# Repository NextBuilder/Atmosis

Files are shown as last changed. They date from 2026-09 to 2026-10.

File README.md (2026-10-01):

<div align="center">

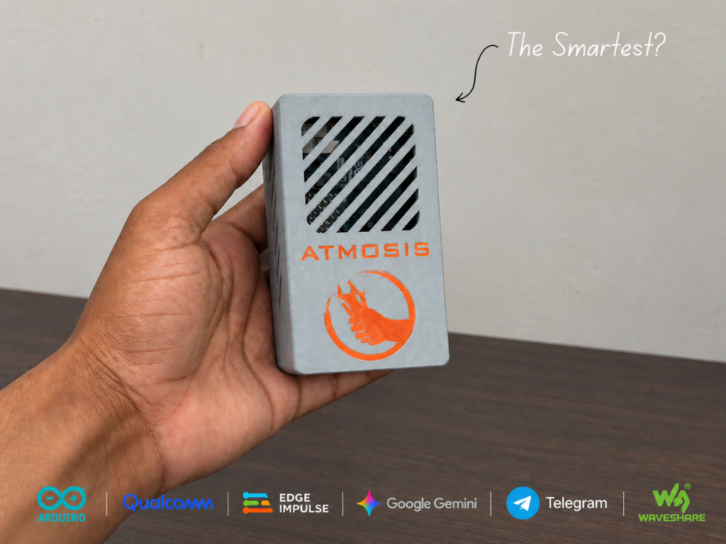
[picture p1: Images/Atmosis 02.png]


# Atmosis

**Real-world air intelligence, built on the Arduino UNO Q**

youtube (https://youtube.com/@NextBuilderIO)
instagram (https://instagram.com/next_builder)
x (https://x.com/NEXTBUILDERIO)
linkedin (https://www.linkedin.com/company/nextbuilderIO/)
instructables (https://www.instructables.com/member/Next%20Builder%20DIY/)
hackster (https://hackster.io/NEXTBUILDER)
hackaday (https://hackaday.io/NextBuilder)

</div>

## Overview

The air around us rarely announces itself. Exhaust from a busy road, dust from a building site, smoke from burning leaves, fumes from a kitchen, or a closed room slowly running out of fresh air — most of it is invisible, and almost none of it is measured.

**Atmosis** is a small device that watches the air every second and tells you what's going on. It turns nine sensor readings into one simple **air score from 1 to 100**, recognises the situation behind the numbers with an **Edge Impulse** model, and uses **Gemini 3.5 Flash** to suggest exactly what to do — on a live dashboard and on your phone through **Telegram**.

The safety features run on the board itself, so the light strip and the dust and carbon-monoxide alarms keep working even without the app or the internet.

## Highlights

- **Nine live readings** — IAQ, VOCs, formaldehyde, CO, PM2.5, temperature, humidity, pressure and altitude
- **Seven air patterns** — an Edge Impulse model trained on real data, from clean air to traffic, dust and smoke
- **Smart advice** — Gemini 3.5 Flash speaks up only when the air needs attention
- **Instant alerts** — clean Telegram cards and a daily air report
- **Live dashboard** — glass-style web app in light and dark themes
- **Works offline** — air score, light and alarms run on the microcontroller

## Dashboard

<div align="center">
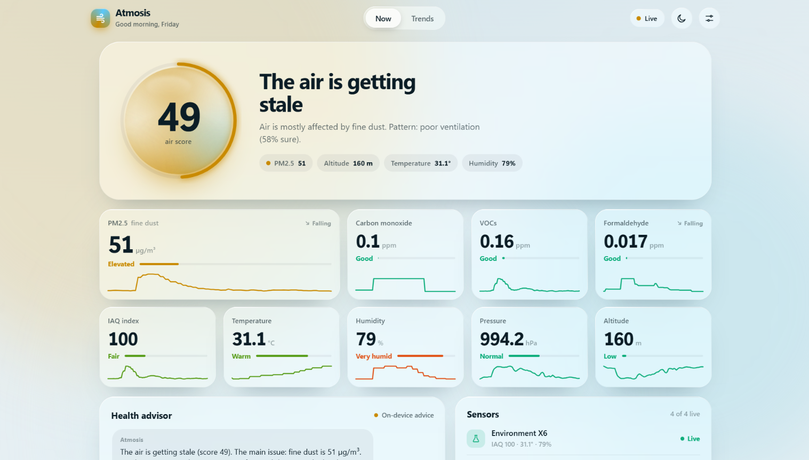
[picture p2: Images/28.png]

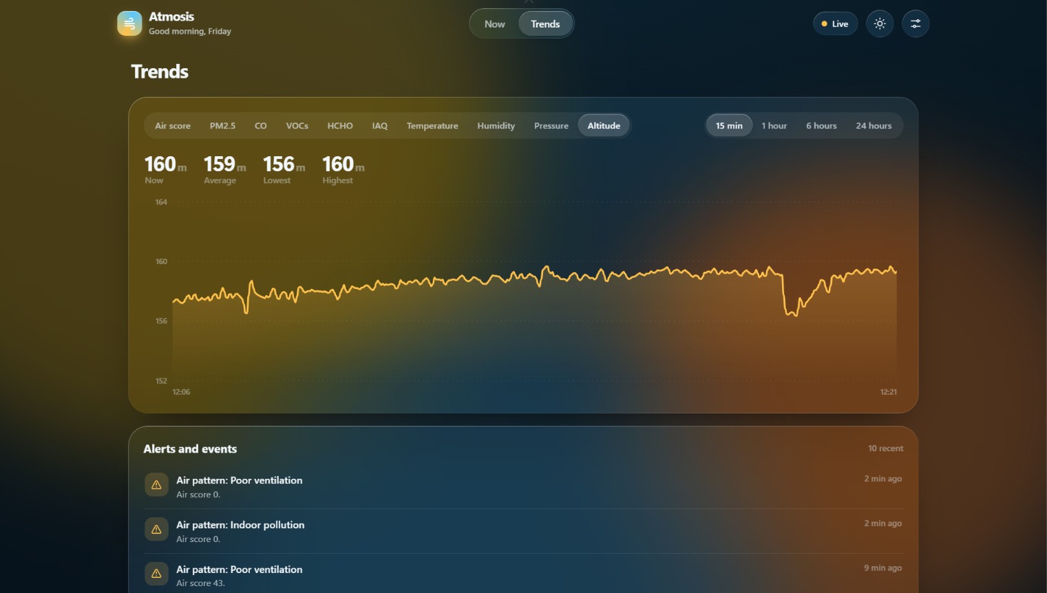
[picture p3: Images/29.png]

<br/>
<sub>Air score, live sensor tiles, Gemini health advisor and trends — in light and dark themes</sub>
</div>

## Telegram Alerts

<div align="center">
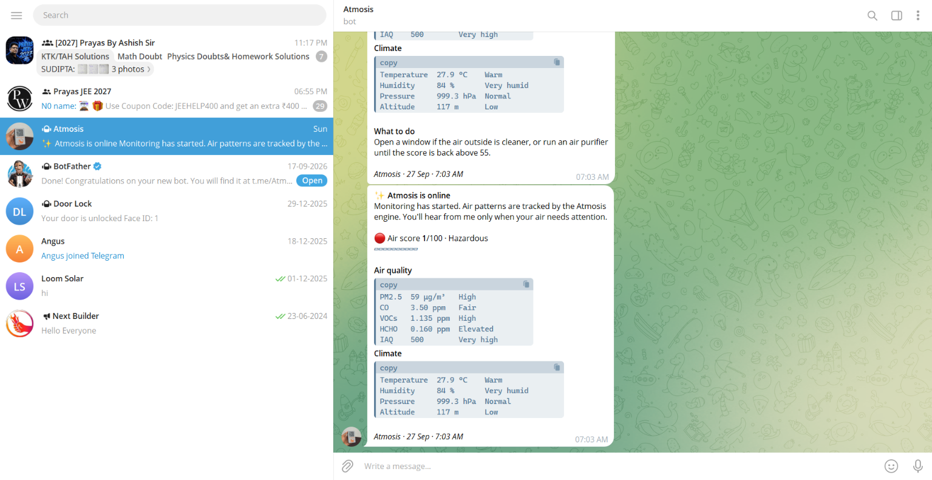
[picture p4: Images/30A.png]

</div>

Every alert is a short card with the air score, all readings, one clear action and a tip from Gemini.

| When | Alert |
|---|---|
| Air score drops to 35 | Air quality needs attention |
| PM2.5 goes above 150 µg/m³ | Very high dust level |
| CO goes above 9 ppm | Carbon monoxide alert, sent instantly |
| Indoor pollution or poor ventilation detected | Air pattern alert |
| Board silent for 2 minutes | Sensors offline |
| Every evening at 9 PM | Daily report with averages and peaks |

## How It Works

<div align="center">
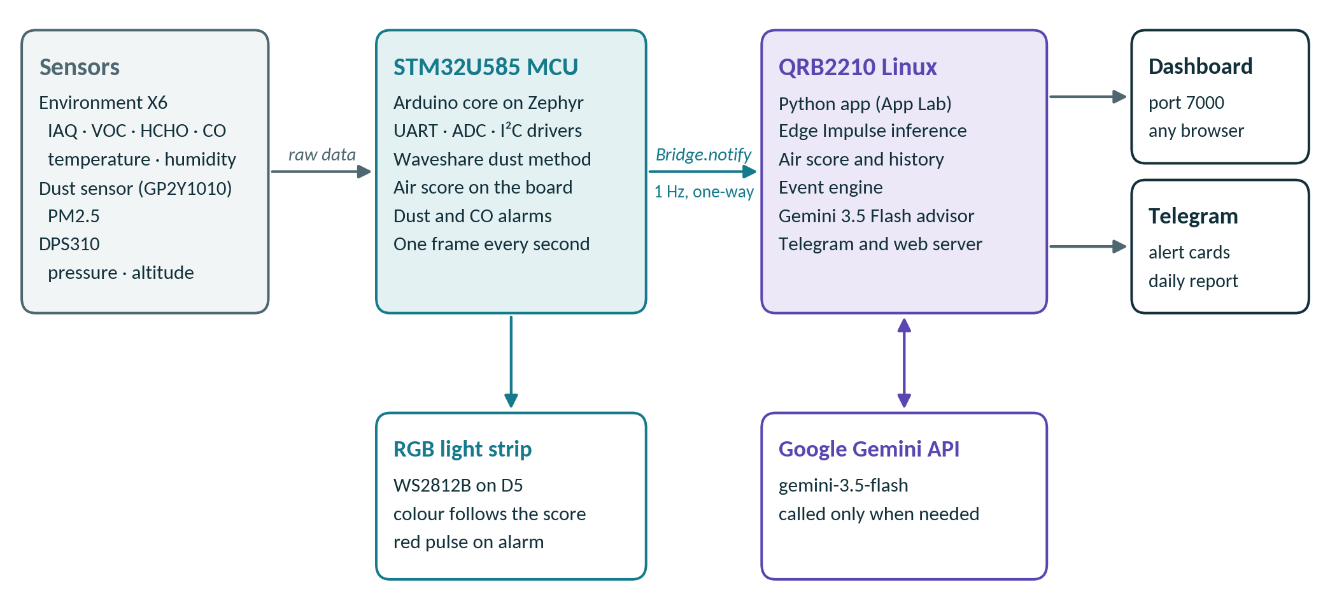
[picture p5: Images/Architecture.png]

</div>

The **Arduino UNO Q** has two processors on one board, and Atmosis uses both:

- **STM32U585 microcontroller** — reads the sensors, calculates the air score, drives the light strip and handles the safety alarms.
- **Qualcomm QRB2210 running Linux** — runs Edge Impulse, the Gemini advisor, Telegram and the dashboard.

Once a second, the microcontroller sends a fresh set of readings to Linux. Nothing is ever sent back, so the board stays safe on its own.

## Edge Impulse

<div align="center">
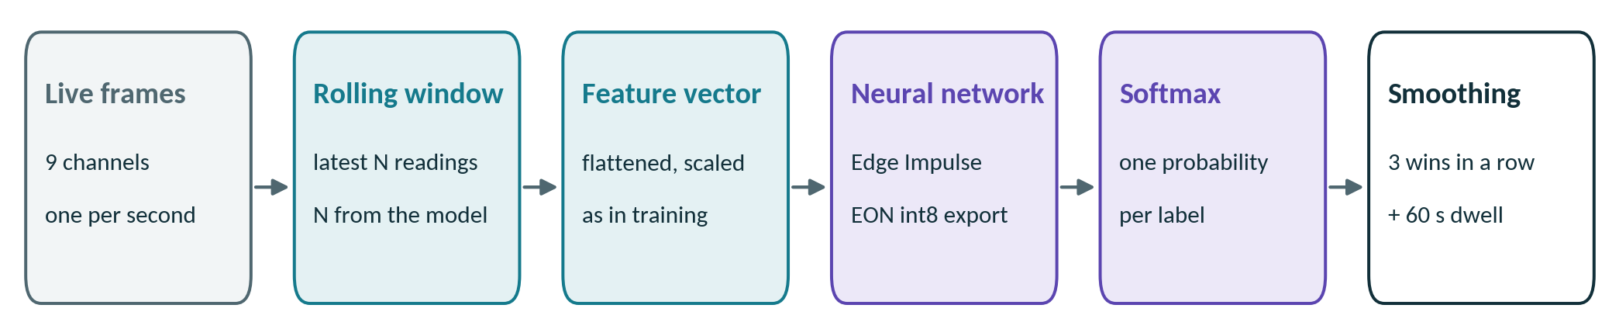
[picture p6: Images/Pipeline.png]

<br/>
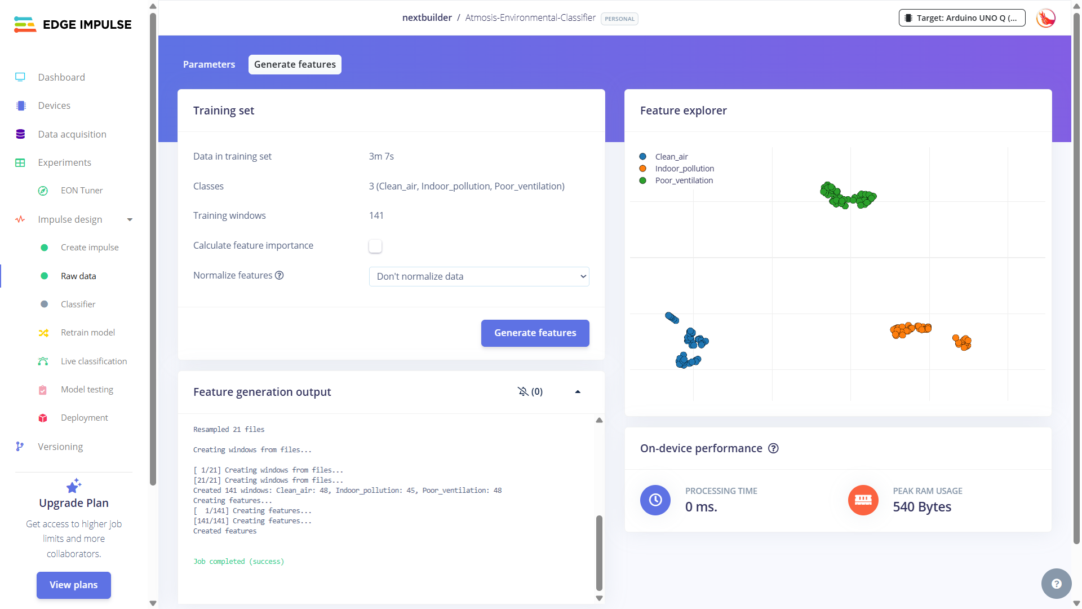
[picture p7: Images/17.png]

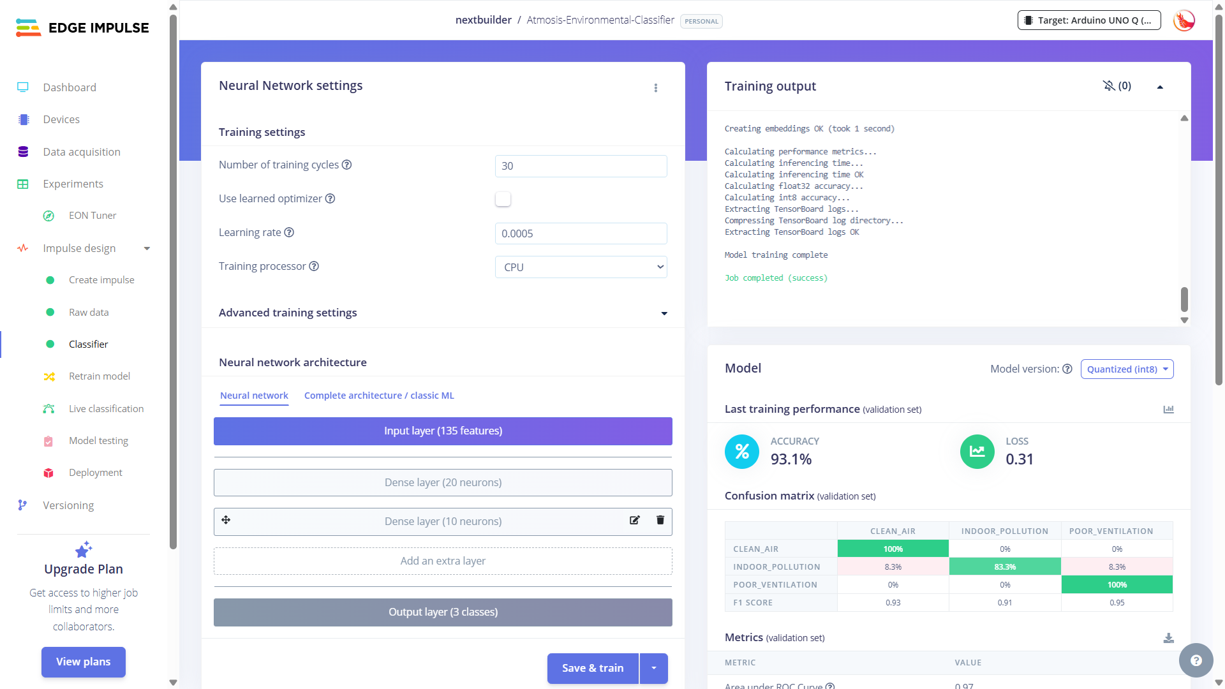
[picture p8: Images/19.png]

</div>

The model was trained on real data recorded with this exact hardware. A data-collection sketch logged all nine readings at 5 Hz, and each pattern was captured in genuine, safe conditions.

| Pattern | Recorded in |
|---|---|
| Clean air | Normal indoor air at different times and places |
| Traffic pollution | Short sessions near a busy road |
| Construction dust | Real construction or dusty sites |
| Indoor pollution | Cooking, incense and similar household sources |
| Poor ventilation | Closed rooms where the air slowly goes stale |
| Biomass burning | Naturally occurring smoke |
| Unusual event | Real anomalies that don't fit the other patterns |

The model runs directly on the UNO Q. To avoid false alarms, a new pattern has to show up three times in a row and hold for a minute before Atmosis reports it.

## Hardware

<div align="center">
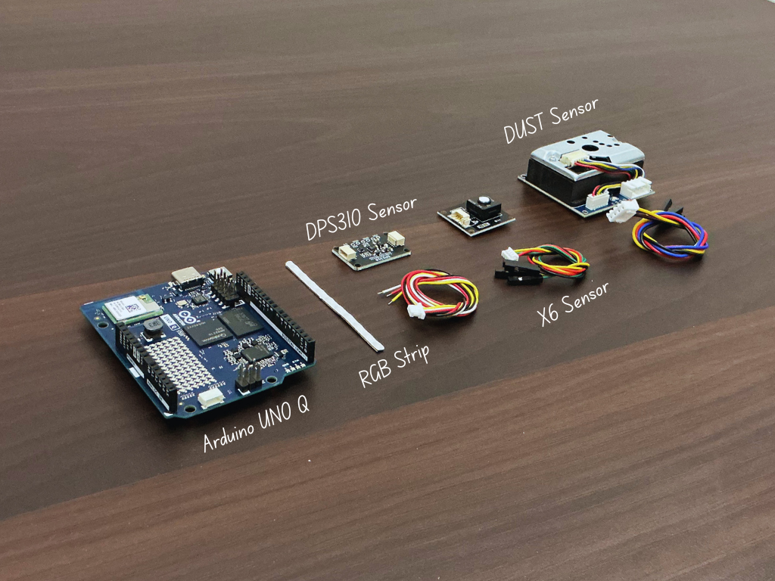
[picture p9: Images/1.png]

</div>

| Component | Purpose | Link |
|---|---|---|
| Arduino UNO Q | Main board | [Amazon](https://www.amazon.com/ABX00173-Dragonwing-microprocessor-STM32U585-Microcontroller/dp/B0GFN669S4/) |
| Waveshare Environment X6 | Gases, temperature, humidity | [Waveshare](https://www.waveshare.com/environment-x6-sensor.htm?&aff_id=135301) |
| Waveshare Dust Sensor | PM2.5 dust | [Waveshare](https://www.waveshare.com/dust-sensor.htm?&aff_id=135301) |
| DPS310 Pressure Sensor | Pressure and altitude | [Amazon](https://www.amazon.com/Industrial-Temperature-Supporting-Microcontrollers-Measurement/dp/B0H5NQJ7RR/) |
| Waveshare RGB COB Strip | Air-quality light | [Waveshare](https://www.waveshare.com/rgb-27-5v-160d.htm?sku=34160?&aff_id=135301) |

## Wiring

<div align="center">
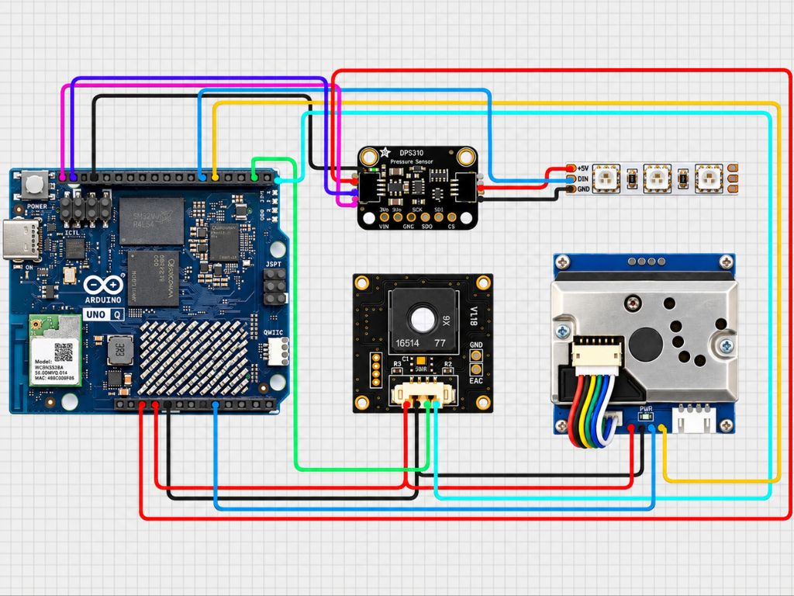
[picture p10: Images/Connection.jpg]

</div>

| Module | Power | Signal |
|---|---|---|
| **Environment X6** | 5V · GND | TXD → D0 · RXD → D1 |
| **Dust Sensor** | 5V · GND | ILED → D4 · AOUT → A0 |
| **DPS310** | 3.3V · GND | SDI → SDA · SCK → SCL |
| **RGB Strip** | 5V · GND | DIN → D5 |

> **Tip:** On the SmartElex DPS310, `SCK` is the clock pin and `SDI` is the data pin. Leave `SDO` and `CS` unconnected.

## Enclosure

<div align="center">
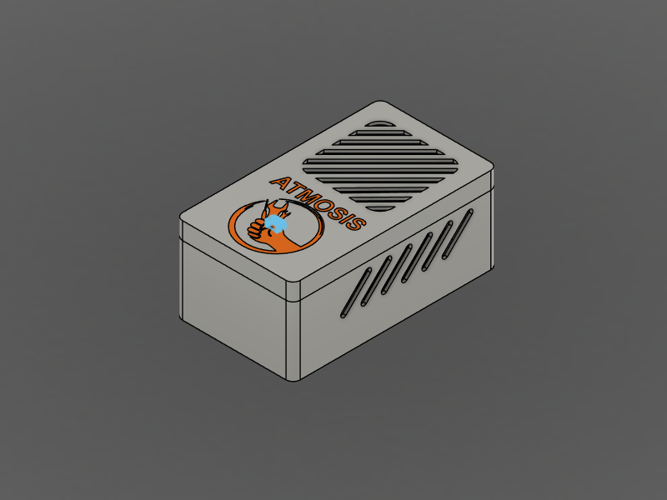
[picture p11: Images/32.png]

<br/>
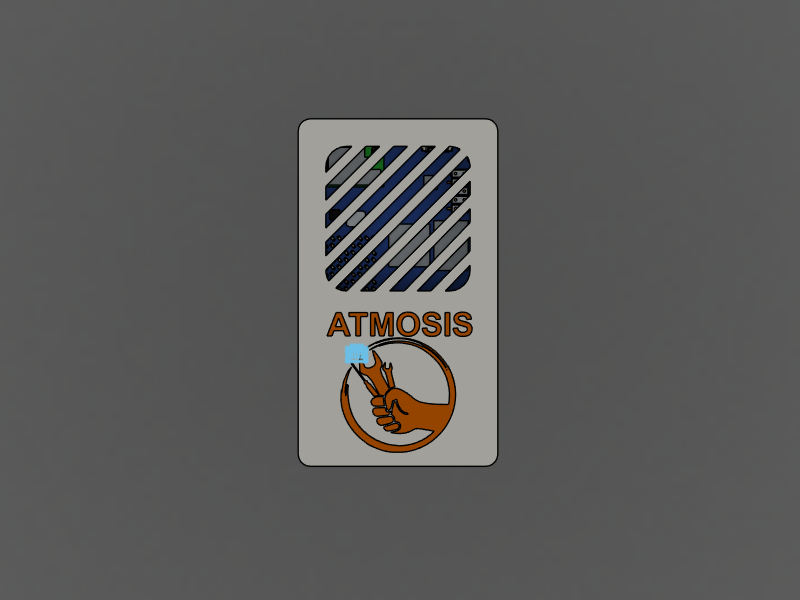
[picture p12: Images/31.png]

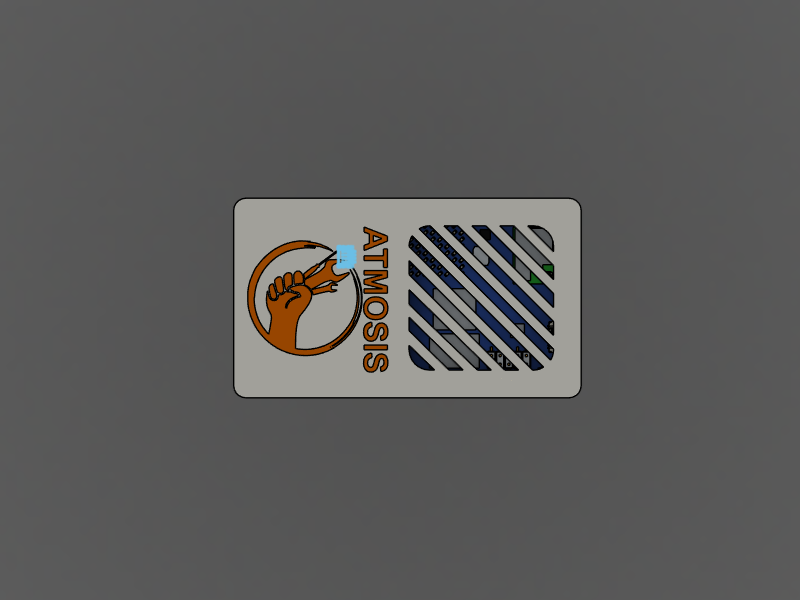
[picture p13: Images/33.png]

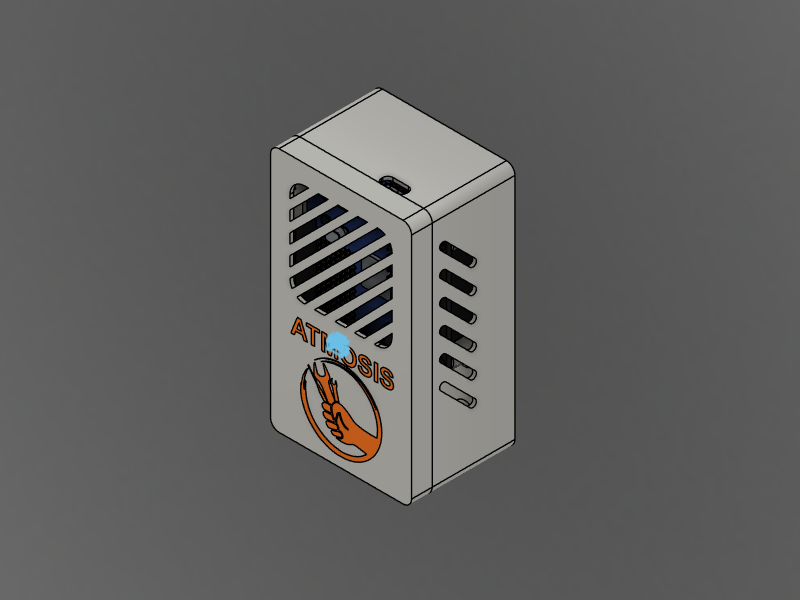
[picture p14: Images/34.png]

</div>

A compact two-part 3D-printed case, designed around the UNO Q and all three sensors. Angled slots on the front and sides let room air flow across the sensors, and the lid comes off easily for wiring. The CAD files are in the [`CAD Design`](CAD%20Design) folder.

<div align="center">
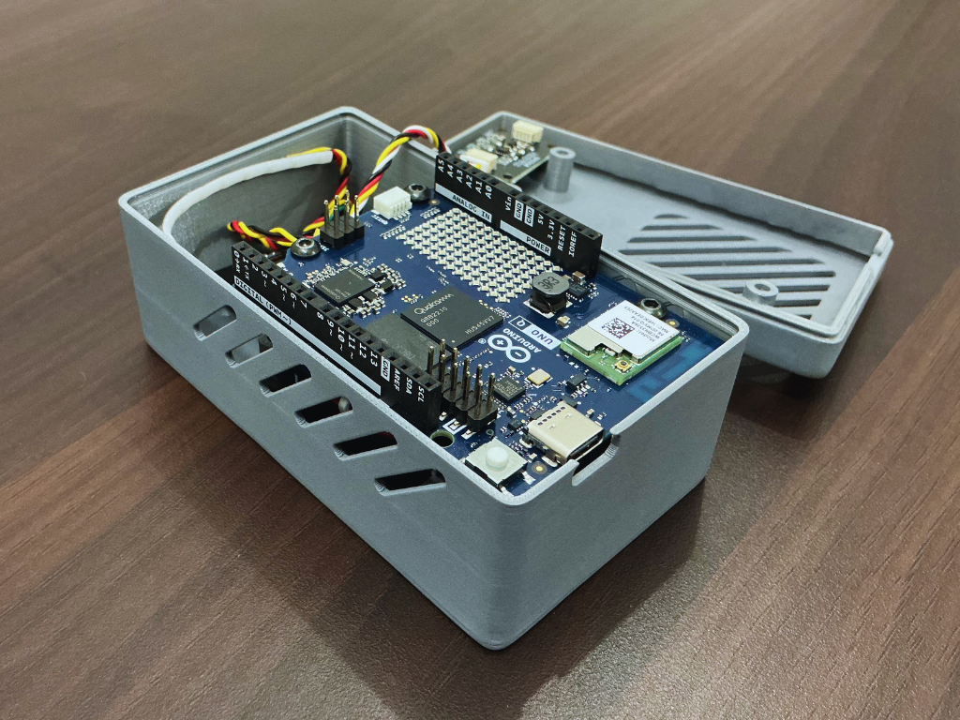
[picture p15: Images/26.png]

<br/>
<sub>Inside, after wiring and assembly</sub>
</div>

## Getting Started

1. Download the latest version from [Releases](https://github.com/NextBuilder/Atmosis/releases/latest).
2. Open `python/.env` and paste your Gemini API key, Telegram bot token and chat ID.
3. Import the folder into **Arduino App Lab** and press **Run**.
4. Open `http://<board-ip>:7000` on any device on the same Wi-Fi.

Full setup and troubleshooting are in the [App Lab guide](Arduino%20App%20Lab).

## Repository

| Folder | Contents |
|---|---|
| [`Arduino App Lab`](Arduino%20App%20Lab) | Firmware, Python app, dashboard and Edge Impulse model |
| [`Data Collection Code`](Data%20Collection%20Code) | Sketch used to record the training data |
| [`Circuit Diagram`](Circuit%20Diagram) | Wiring diagram |
| [`CAD Design`](CAD%20Design) | 3D-printable enclosure |
| [`Images`](Images) | Photos and screenshots |

## In Action

<div align="center">

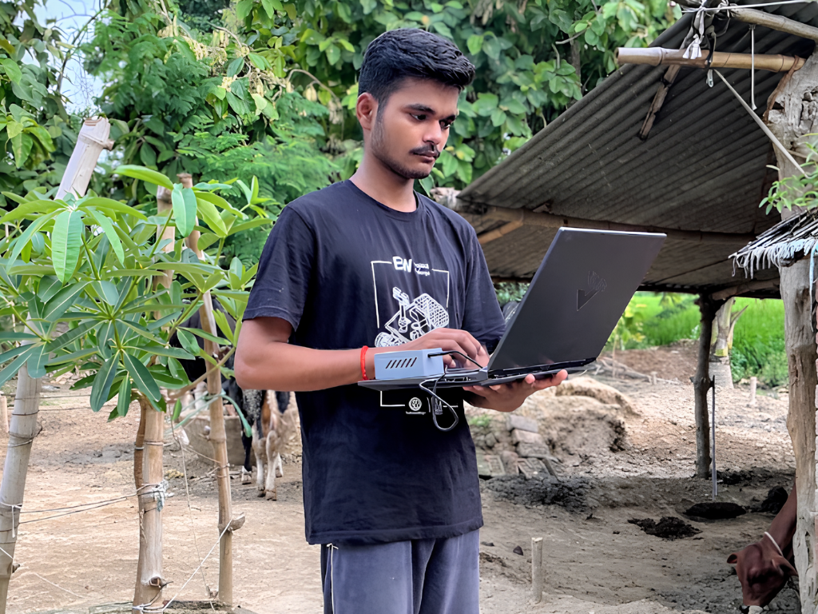
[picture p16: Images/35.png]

</div>

## Build Guide

Step-by-step instructions, assembly photos and testing are available on:

- **Instructables** — https://www.instructables.com/member/Next%20Builder%20DIY/
- **Hackster.io** — https://hackster.io/NEXTBUILDER
- **Hackaday.io** — https://hackaday.io/NextBuilder

## License

Released under the [MIT License](LICENSE).

<div align="center">
<br/>

Built with ❤️ by **[Next Builder](https://youtube.com/@nextbuilderio)**

*Built one? Share it — open an issue, tag us, or drop a photo.*

*⭐ Star this repo if it helped you build something awesome ⭐*

</div>

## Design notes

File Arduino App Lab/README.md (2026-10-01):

# Atmosis

**Indoor air quality you can see, understand and act on — running on the Arduino UNO Q.**

Most homes have a smoke alarm for the worst day and nothing for every other day. Atmosis watches the air in a room every second — fine dust, carbon monoxide, VOCs and formaldehyde — turns it into a single air score, recognises what is happening with an Edge Impulse model, and tells you what to do about it.

- **Real-time sensing** — nine readings per second from three sensors
- **On-board safety** — the air score, light strip and dust / CO alarms run on the microcontroller, independent of the app and the network
- **Edge Impulse** — recognises seven air conditions, from clean air and poor ventilation to traffic pollution and biomass smoke
- **Gemini 3.5 Flash advisor** — short, specific advice, only when the air needs attention
- **Telegram alerts** — structured cards with rate limiting, plus a daily report
- **Live dashboard** — on any phone or laptop on the same network

---

## Architecture

```
 Environment X6 ─┐
 Dust sensor    ─┼─►  STM32U585 · Zephyr  ──── Bridge.notify, 1 Hz ────►  QRB2210 · Linux
 DPS310         ─┘    air score · alarms                                   Edge Impulse inference
                      WS2812B light strip                                  Gemini advisor · Telegram
                                                                           Dashboard on :7000
```

```
sketch/    Firmware — sensor drivers, air score, light strip, alarms
python/    App — dashboard, Edge Impulse inference, Gemini advisor, Telegram
scripts/   Firmware simulator tests and Cortex-M33 build check
```

---

## Hardware

| Part | Link |
|---|---|
| Arduino UNO Q | [Amazon](https://www.amazon.com/ABX00173-Dragonwing-microprocessor-STM32U585-Microcontroller/dp/B0GFN669S4/) |
| DPS310 pressure sensor | [Amazon](https://www.amazon.com/Industrial-Temperature-Supporting-Microcontrollers-Measurement/dp/B0H5NQJ7RR/) |
| Waveshare Environment X6 | [Waveshare](https://www.waveshare.com/environment-x6-sensor.htm?&aff_id=135301) |
| Waveshare Dust Sensor | [Waveshare](https://www.waveshare.com/dust-sensor.htm?&aff_id=135301) |
| Waveshare RGB COB strip (WS2812B) | [Waveshare](https://www.waveshare.com/rgb-27-5v-160d.htm?sku=34160?&aff_id=135301) |

---

## Getting started

**1. Add your keys** to `python/.env`. Any feature left on its placeholder stays switched off.

| Key | Where to get it |
|---|---|
| `GEMINI_API_KEY` | [aistudio.google.com/apikey](https://aistudio.google.com/apikey) |
| `TELEGRAM_BOT_TOKEN` | Telegram → @BotFather → `/newbot` |
| `TELEGRAM_CHAT_ID` | Telegram → @userinfobot |

Open your new bot in Telegram and press **Start**, otherwise it cannot message you.

**2. Run** — import this folder into Arduino App Lab and press **Run**.

**3. Open** — `http://<board-ip>:7000` from any device on the same Wi-Fi.

---

## How it works

### Sensing

| Sensor | Readings | Method |
|---|---|---|
| Environment X6 | IAQ, VOCs, formaldehyde, CO, temperature, humidity | Waveshare UART protocol (`0x70` query, checksum-verified 22-byte frame) |
| Dust sensor | PM2.5 | Waveshare reference method — sample 280 µs after the LED pulse, 11:1 divider, 400 mV zero, 0.2 µg/m³ per mV, 10-reading average |
| DPS310 | Pressure, altitude | Adafruit DPS310 library, 4 Hz × 16 oversampling, automatic retry every 10 s |

The **air score** (1–100) is the lowest of the pollutant sub-scores — PM2.5, CO, VOCs, formaldehyde and IAQ — using WHO / EPA indoor breakpoints.

### Board ↔ Linux link

The microcontroller pushes one frame per second to Python with `Bridge.notify`, and nothing is ever sent back. On the UNO Q, messages addressed to the board are handled on a small thread stack; keeping the link one-way removes that failure mode entirely and keeps the board fully self-sufficient — the light strip and alarms keep working even when the app is stopped.

### Edge Impulse

Atmosis uses an Edge Impulse classifier trained on real data recorded with this exact sensor setup. A dedicated data-collection sketch streamed all nine readings as CSV at 5 Hz, and each class was captured under genuine, safe conditions.

| Class | Condition |
|---|---|
| `Clean_air` | Normal, relatively clean indoor air, recorded at different times and locations to set the baseline |
| `Traffic_pollution` | Short recordings near a busy road with passing traffic |
| `Construction_dust` | Genuine construction or dusty environments, recorded only when safely available |
| `Indoor_pollution` | Brief, controlled household sources such as cooking or incense |
| `Poor_ventilation` | Closed rooms with limited airflow, where air quality degrades gradually |
| `Biomass_burning` | Naturally occurring burning or smoke, captured only when safe |
| `Unusual_event` | Genuine anomalies that don't fit the other classes |

**Impulse:** nine time-series axes (`iaq`, `tvoc_ppm`, `hcho_ppm`, `co_ppm`, `temp_c`, `rh_pct`, `dust_ugm3`, `pressure_hpa`, `altitude_m`) → Raw Data block → dense neural-network classifier → int8, EON Compiler.

**On the board:** Atmosis reads the exported C++ library directly in Python — no compile step. A rolling window of live readings is classified once per frame, and a new label must win three windows in a row and hold for 60 seconds before anything changes. The model is verified against reference situations at start-up; if the files are missing or fail the check, a threshold-based pattern engine takes over.

To update the model, copy `model_metadata.h`, `model_variables.h` and `tflite_learn_*_compiled.cpp` into `python/model/` and restart.

### Gemini advisor

The Health advisor is written by Gemini 3.5 Flash when the air starts needing attention, refreshed only if it gets worse (at most every 5 minutes) or after 30 minutes. Gemini sees its previous advice so it doesn't repeat itself; when the air is healthy the card simply reads **All clear**. If the service is busy, Atmosis backs off and retries on its own.

### Telegram

| Trigger | Message |
|---|---|
| App starts | Atmosis is online |
| Air score ≤ 35 / recovers above 55 | Air quality needs attention / has recovered |
| PM2.5 above 150 µg/m³ | Very high dust level / back to safe |
| CO above 9 ppm | Carbon monoxide alert — sent immediately |
| Edge Impulse detects indoor pollution or poor ventilation | Pattern alert, at most every 30 minutes |
| Air stays poor | Reminder, at most once an hour |
| Board silent for 2 minutes | Sensors not responding / reconnected |
| Daily at 9 PM | Air report — averages, peaks and the worst time of day |

Alerts are spaced at least 10 minutes apart (dust: 15), so a reading hovering near a threshold never floods the chat.

---

## Configuration

Optional settings in `python/.env`:

| Setting | Default | Description |
|---|---|---|
| `ATMOSIS_AI_PROVIDER` | `auto` | `off` disables the Gemini advisor |
| `GEMINI_MODEL` | `gemini-3.5-flash` | Model used for advice and questions |
| `ATMOSIS_FAILSAFE_CO_PPM` | `9` | Carbon-monoxide alert level |
| `ATMOSIS_NOTIFY_REMINDER_S` | `3600` | Minimum gap between "still poor" reminders |
| `ATMOSIS_NOTIFY_DAILY_HOUR` | `21` | Hour of the daily report (`-1` to disable) |
| `ATMOSIS_UTC_OFFSET_MIN` | `330` | Time zone for message timestamps |
| `ATMOSIS_DASHBOARD_URL` | auto | Dashboard link used in Telegram messages |
| `ATMOSIS_SIMULATE` | `0` | `1` runs the full app on simulated data |

---

## Testing

```bash
./scripts/check_firmware.sh             # firmware simulator + Cortex-M33 build check
cd python && python3 test_atmosis.py    # application tests
ATMOSIS_SIMULATE=1 python3 main.py      # full app without hardware
```

---

## Troubleshooting

| Symptom | Fix |
|---|---|
| Board offline | Press **Stop**, then **Run** in App Lab, and check the board has power |
| Gas sensor: no data | X6 `TXD → D0`, `RXD → D1` (crossed), `VCC → 5V` |
| Dust: no signal | `AOUT → A0`, `VCC → 5V` — 3.3V is not enough for this sensor |
| DPS310 not found | Check `SCK → SCL`, `SDI → SDA`, `VIN → 3.3V`; power-cycle the board for 10 s, then Run |
| Advisor shows "reconnecting" | Gemini is busy or slow — Atmosis retries automatically |
| No readings from the first second | Known issue on some UNO Q cores where `Serial1.begin()` affects the Bridge — see [Arduino_RouterBridge#76](https://github.com/arduino-libraries/Arduino_RouterBridge/issues/76) |

---

## Dependencies

Installed automatically by App Lab from `sketch/sketch.yaml`:
Adafruit DPS310 1.1.6 · Adafruit BusIO 1.17.3 · Adafruit Unified Sensor 1.1.15 · Adafruit NeoPixel 1.15.5

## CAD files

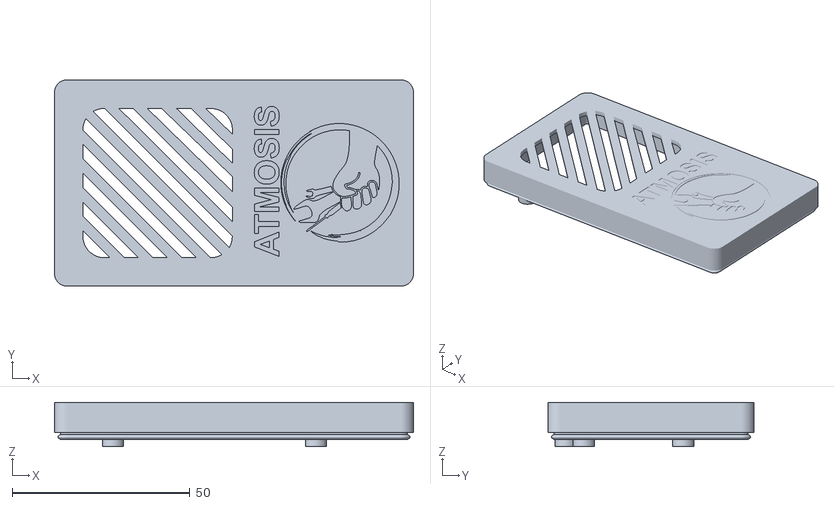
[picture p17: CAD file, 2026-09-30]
CAD Design/Cover.stl
101.0 x 58.0 x 12.5

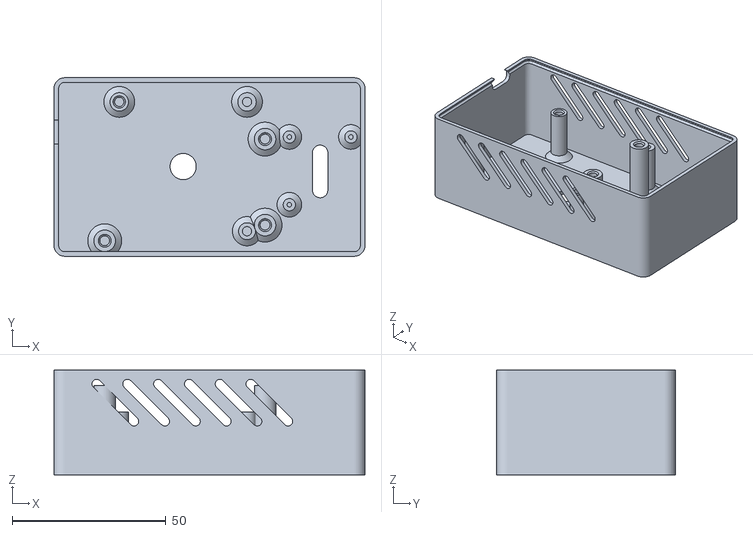
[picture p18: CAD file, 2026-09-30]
CAD Design/Housing.stl
101.0 x 58.0 x 34.0

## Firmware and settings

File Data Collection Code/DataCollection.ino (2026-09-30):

#include <Arduino.h>
#include <Wire.h>
#include <Adafruit_DPS310.h>
#include <math.h>
#include <string.h>

namespace config {

constexpr uint32_t kSerialBaud = 115200;
constexpr uint32_t kSerialWaitMs = 5000;
constexpr uint32_t kPollIntervalMs = 200;
constexpr uint32_t kStaleAfterMs = 3000;
constexpr uint32_t kDiagnosticsIntervalMs = 1000;
constexpr bool kDiagnosticsMode = false;

namespace adc {
constexpr uint8_t kResolutionBits = 12;
constexpr int kMaxCount = (1 << kResolutionBits) - 1;
constexpr float kReferenceVolts = 3.3f;
}

namespace x6 {
constexpr uint32_t kBaud = 9600;
constexpr uint32_t kResponseTimeoutMs = 500;
constexpr float kMinTemperatureC = -40.0f;
constexpr float kMaxTemperatureC = 85.0f;
}

namespace dust {
const uint8_t kLedPin = 4;
const uint8_t kOutputPin = A0;
constexpr auto kLedOn = HIGH;
constexpr auto kLedOff = LOW;
constexpr uint8_t kSamplesPerRead = 20;
constexpr uint8_t kTrimPerSide = 4;
constexpr float kFilterAlpha = 0.25f;
constexpr uint32_t kFilterResetMs = 10000;
constexpr float kModuleGain = 11.0f;
constexpr float kZeroDustVolts = 0.6f;
constexpr float kUgm3PerVolt = 200.0f;
constexpr float kMaxSensorVolts = 5.5f;
constexpr uint32_t kSampleDelayUs = 280;
constexpr uint32_t kPulseWidthUs = 320;
constexpr uint32_t kPulseToleranceUs = 20;
constexpr uint32_t kPulsePeriodUs = 10000;
constexpr int kRailMarginCounts = 2;
}

namespace dps310 {
constexpr uint32_t kI2cClockHz = 100000;
constexpr uint32_t kRetryIntervalMs = 10000;
constexpr uint32_t kReadTimeoutMs = 300;
constexpr uint32_t kWarmupMs = 300;
constexpr uint8_t kMaxConsecutiveFailures = 3;
constexpr float kSeaLevelHpa = 1013.25f;
constexpr float kMinPressureHpa = 300.0f;
constexpr float kMaxPressureHpa = 1200.0f;
constexpr float kMinTemperatureC = -40.0f;
constexpr float kMaxTemperatureC = 85.0f;
}

static_assert(dust::kSamplesPerRead > 2 * dust::kTrimPerSide, "Dust trim removes every sample");
static_assert(dust::kFilterAlpha > 0.0f && dust::kFilterAlpha <= 1.0f, "Dust filter alpha must be in (0, 1]");
static_assert(dust::kSampleDelayUs < dust::kPulseWidthUs, "Dust sample must fall inside the LED pulse");
static_assert(dust::kPulseWidthUs < dust::kPulsePeriodUs, "Dust pulse must fit inside its period");
static_assert(dps310::kSeaLevelHpa >= 800.0f && dps310::kSeaLevelHpa <= 1200.0f, "Sea-level pressure out of range");

}

inline uint32_t nowMs() { return static_cast<uint32_t>(millis()); }
inline uint32_t nowUs() { return static_cast<uint32_t>(micros()); }

struct EnvironmentReading {
  float iaq;
  float tvocPpm;
  float hchoPpm;
  float coPpm;
  float temperatureC;
  float humidityPct;
};

struct DustReading {
  float densityUgm3;
};

struct PressureReading {
  float pressureHpa;
  float temperatureC;
  float altitudeM;
};

template <typename T>
class LiveValue {
 public:
  void update(const T& value) {
    value_ = value;
    updatedAtMs_ = nowMs();
    ++updateCount_;
    hasValue_ = true;
  }

  const T& value() const { return value_; }
  bool hasValue() const { return hasValue_; }
  uint32_t ageMs() const { return hasValue_ ? nowMs() - updatedAtMs_ : 0; }
  bool isFresh() const { return hasValue_ && ageMs() <= config::kStaleAfterMs; }

  uint32_t takeUpdateCount() {
    const uint32_t count = updateCount_;
    updateCount_ = 0;
    return count;
  }

 private:
  T value_{};
  uint32_t updatedAtMs_ = 0;
  uint32_t updateCount_ = 0;
  bool hasValue_ = false;
};

class EnvironmentX6 {
 public:
  explicit EnvironmentX6(HardwareSerial& port) : port_(port) {}

  void begin() { port_.begin(config::x6::kBaud); }

  bool read(EnvironmentReading& out) {
    discardInput();
    sendQuery();

    uint8_t frame[kFrameLength];
    if (!receiveFrame(frame)) return fail();

    const EnvironmentReading reading = decode(frame);
    if (!isPlausible(reading)) return fail();

    out = reading;
    return true;
  }

  uint32_t errorCount() const { return errorCount_; }

 private:
  static constexpr uint8_t kHeader = 0x70;
  static constexpr size_t kFrameLength = 22;

  HardwareSerial& port_;
  uint32_t errorCount_ = 0;

  bool fail() {
    ++errorCount_;
    return false;
  }

  void discardInput() {
    while (port_.available() > 0) port_.read();
  }

  void sendQuery() {
    uint8_t query[2] = {kHeader, 0};
    query[1] = checksum(query, 1);
    port_.write(query, sizeof(query));
  }

  bool receiveFrame(uint8_t* frame) {
    const uint32_t start = nowMs();
    size_t received = 0;

    while (nowMs() - start < config::x6::kResponseTimeoutMs) {
      if (port_.available() <= 0) {
        delay(1);
        continue;
      }

      const uint8_t byte = static_cast<uint8_t>(port_.read());
      if (received == 0 && byte != kHeader) continue;

      frame[received++] = byte;
      if (received < kFrameLength) continue;
      if (checksum(frame, kFrameLength) == 0) return true;

      received = resync(frame);
    }
    return false;
  }

  static size_t resync(uint8_t* frame) {
    size_t next = 1;
    while (next < kFrameLength && frame[next] != kHeader) ++next;
    const size_t kept = kFrameLength - next;
    memmove(frame, frame + next, kept);
    return kept;
  }

  static uint8_t checksum(const uint8_t* data, size_t length) {
    uint8_t sum = 0;
    for (size_t i = 0; i < length; ++i) sum += data[i];
    return static_cast<uint8_t>(0u - sum);
  }

  static uint16_t readUint16(const uint8_t* bytes) {
    return static_cast<uint16_t>((bytes[0] << 8) | bytes[1]);
  }

  static float readFloat(const uint8_t* bytes) {
    const uint32_t raw = (static_cast<uint32_t>(bytes[0]) << 24) |
                         (static_cast<uint32_t>(bytes[1]) << 16) |
                         (static_cast<uint32_t>(bytes[2]) << 8) |
                         static_cast<uint32_t>(bytes[3]);
    float value;
    memcpy(&value, &raw, sizeof(value));
    return value;
  }

  static EnvironmentReading decode(const uint8_t* frame) {
    EnvironmentReading reading;
    reading.iaq = readFloat(frame + 1);
    reading.tvocPpm = readFloat(frame + 5);
    reading.hchoPpm = readFloat(frame + 9);
    reading.coPpm = readFloat(frame + 13);
    reading.temperatureC = static_cast<int16_t>(readUint16(frame + 17)) / 100.0f;
    reading.humidityPct = readUint16(frame + 19) / 100.0f;
    return reading;
  }

  static bool isPlausible(const EnvironmentReading& reading) {
    const float gases[] = {reading.iaq, reading.tvocPpm, reading.hchoPpm, reading.coPpm};
    for (const float gas : gases) {
      if (!isfinite(gas) || gas < 0.0f) return false;
    }
    return reading.temperatureC >= config::x6::kMinTemperatureC &&
           reading.temperatureC <= config::x6::kMaxTemperatureC &&
           reading.humidityPct >= 0.0f && reading.humidityPct <= 100.0f;
  }
};

class DustSensor {
 public:
  DustSensor(uint8_t ledPin, uint8_t outputPin) : ledPin_(ledPin), outputPin_(outputPin) {}

  void begin() {
    pinMode(ledPin_, OUTPUT);
    digitalWrite(ledPin_, config::dust::kLedOff);
    pinMode(outputPin_, INPUT);
    analogRead(outputPin_);
  }

  bool read(DustReading& out) {
    int samples[config::dust::kSamplesPerRead];
    if (!acquire(samples)) return fail();

    const float sensorVolts = toSensorVolts(trimmedMean(samples));
    if (!isfinite(sensorVolts) || sensorVolts > config::dust::kMaxSensorVolts) return fail();

    out.densityUgm3 = smooth(toDensity(sensorVolts));
    return true;
  }

  uint32_t errorCount() const { return errorCount_; }

 private:
  const uint8_t ledPin_;
  const uint8_t outputPin_;
  float estimate_ = 0.0f;
  bool filterReady_ = false;
  uint32_t lastValidMs_ = 0;
  uint32_t errorCount_ = 0;

  bool fail() {
    filterReady_ = false;
    ++errorCount_;
    return false;
  }

  bool acquire(int* samples) {
    using namespace config::dust;
    bool valid = true;

    for (uint8_t i = 0; i < kSamplesPerRead; ++i) {
      digitalWrite(ledPin_, kLedOn);
      const uint32_t pulseStart = nowUs();
      waitUntil(pulseStart, kSampleDelayUs);
      samples[i] = analogRead(outputPin_);
      waitUntil(pulseStart, kPulseWidthUs);
      digitalWrite(ledPin_, kLedOff);

      const uint32_t pulseUs = nowUs() - pulseStart;
      valid = valid && isPulseOnTime(pulseUs) && isAwayFromRails(samples[i]);

      const uint32_t elapsedUs = nowUs() - pulseStart;
      if (elapsedUs < kPulsePeriodUs) delayMicroseconds(kPulsePeriodUs - elapsedUs);
    }
    return valid;
  }

  static void waitUntil(uint32_t start, uint32_t offsetUs) {
    while (nowUs() - start < offsetUs) {
    }
  }

  static bool isPulseOnTime(uint32_t pulseUs) {
    using namespace config::dust;
    return pulseUs >= kPulseWidthUs - kPulseToleranceUs &&
           pulseUs <= kPulseWidthUs + kPulseToleranceUs;
  }

  static bool isAwayFromRails(int raw) {
    using namespace config;
    return raw > dust::kRailMarginCounts && raw < adc::kMaxCount - dust::kRailMarginCounts;
  }

  static float trimmedMean(int* samples) {
    using namespace config::dust;
    for (uint8_t i = 1; i < kSamplesPerRead; ++i) {
      const int value = samples[i];
      uint8_t j = i;
      while (j > 0 && samples[j - 1] > value) {
        samples[j] = samples[j - 1];
        --j;
      }
      samples[j] = value;
    }

    float sum = 0.0f;
    for (uint8_t i = kTrimPerSide; i < kSamplesPerRead - kTrimPerSide; ++i) sum += samples[i];
    return sum / (kSamplesPerRead - 2 * kTrimPerSide);
  }

  static float toSensorVolts(float rawAverage) {
    using namespace config;
    return rawAverage * adc::kReferenceVolts / adc::kMaxCount * dust::kModuleGain;
  }

  static float toDensity(float sensorVolts) {
    using namespace config::dust;
    const float density = (sensorVolts - kZeroDustVolts) * kUgm3PerVolt;
    return density > 0.0f ? density : 0.0f;
  }

  float smooth(float instant) {
    using namespace config::dust;
    const uint32_t now = nowMs();
    if (!filterReady_ || now - lastValidMs_ > kFilterResetMs) {
      estimate_ = instant;
      filterReady_ = true;
    } else {
      estimate_ += kFilterAlpha * (instant - estimate_);
    }
    lastValidMs_ = now;
    return estimate_;
  }
};

float altitudeFromPressure(float pressureHpa, float seaLevelHpa) {
  constexpr float kExponent = 0.1903f;
  constexpr float kScaleMeters = 44330.0f;
  constexpr int kSeriesTerms = 64;

  const float x = pressureHpa / seaLevelHpa - 1.0f;
  float term = 1.0f;
  float ratioPowerMinusOne = 0.0f;
  for (int n = 1; n <= kSeriesTerms; ++n) {
    term *= (kExponent - (n - 1)) * x / n;
    ratioPowerMinusOne += term;
  }
  return -kScaleMeters * ratioPowerMinusOne;
}

class PressureSensorDps310 {
 public:
  explicit PressureSensorDps310(TwoWire& wire) : wire_(wire) {}

  bool begin() {
    active_ = nullptr;
    address_ = 0;
    lastAttemptMs_ = nowMs();

    wire_.begin();
    wire_.setClock(config::dps310::kI2cClockHz);

    Adafruit_DPS310* const drivers[] = {&driverAt77_, &driverAt76_};
    const uint8_t addresses[] = {0x77, 0x76};

    for (uint8_t i = 0; i < 2; ++i) {
      if (!configure(*drivers[i], addresses[i])) continue;
      active_ = drivers[i];
      address_ = addresses[i];
      failures_ = 0;
      return true;
    }
    return false;
  }

  bool read(PressureReading& out) {
    if (!active_ && !reconnect()) return false;
    if (!waitForData()) return fail();

    sensors_event_t temperature = {};
    sensors_event_t pressure = {};
    if (!active_->getEvents(&temperature, &pressure)) return fail();

    PressureReading reading;
    reading.pressureHpa = pressure.pressure;
    reading.temperatureC = temperature.temperature;
    if (!isPlausible(reading)) return fail();

    reading.altitudeM = altitudeFromPressure(reading.pressureHpa, config::dps310::kSeaLevelHpa);
    failures_ = 0;
    out = reading;
    return true;
  }

  uint32_t errorCount() const { return errorCount_; }

 private:
  static constexpr uint8_t kRegMeasCfg = 0x08;
  static constexpr uint8_t kRegProductId = 0x0D;
  static constexpr uint8_t kProductId = 0x10;
  static constexpr uint8_t kDataReadyMask = 0x30;

  TwoWire& wire_;
  Adafruit_DPS310 driverAt77_;
  Adafruit_DPS310 driverAt76_;
  Adafruit_DPS310* active_ = nullptr;
  uint8_t address_ = 0;
  uint8_t failures_ = 0;
  uint32_t lastAttemptMs_ = 0;
  uint32_t errorCount_ = 0;

  bool configure(Adafruit_DPS310& driver, uint8_t address) {
    uint8_t productId = 0;
    if (!readRegister(address, kRegProductId, productId) || productId != kProductId) return false;
    if (!driver.begin_I2C(address, &wire_)) return false;

    driver.setMode(DPS310_IDLE);
    if (!applyTemperatureFix(address)) return false;
    driver.configurePressure(DPS310_4HZ, DPS310_16SAMPLES);
    driver.configureTemperature(DPS310_4HZ, DPS310_16SAMPLES);
    driver.setMode(DPS310_CONT_PRESTEMP);

    sensors_event_t temperature = {};
    sensors_event_t pressure = {};
    driver.getEvents(&temperature, &pressure);
    delay(config::dps310::kWarmupMs);
    return true;
  }

  bool reconnect() {
    if (nowMs() - lastAttemptMs_ < config::dps310::kRetryIntervalMs) return false;
    return begin();
  }

  bool waitForData() {
    const uint32_t start = nowMs();
    while (true) {
      uint8_t status = 0;
      if (!readRegister(address_, kRegMeasCfg, status)) return false;
      if ((status & kDataReadyMask) == kDataReadyMask) return true;
      if (nowMs() - start >= config::dps310::kReadTimeoutMs) return false;
      delay(2);
    }
  }

  bool applyTemperatureFix(uint8_t address) {
    const uint8_t sequence[][2] = {{0x0E, 0xA5}, {0x0F, 0x96}, {0x62, 0x02}, {0x0E, 0x00}, {0x0F, 0x00}};
    bool ok = true;
    for (const auto& step : sequence) ok = writeRegister(address, step[0], step[1]) && ok;
    return ok;
  }

  bool readRegister(uint8_t address, uint8_t reg, uint8_t& value) {
    wire_.beginTransmission(address);
    wire_.write(reg);
    if (wire_.endTransmission() != 0) return false;
    if (wire_.requestFrom(address, static_cast<size_t>(1)) != 1) return false;
    value = static_cast<uint8_t>(wire_.read());
    return true;
  }

  bool writeRegister(uint8_t address, uint8_t reg, uint8_t value) {
    wire_.beginTransmission(address);
    wire_.write(reg);
    wire_.write(value);
    return wire_.endTransmission() == 0;
  }

  static bool isPlausible(const PressureReading& reading) {
    using namespace config::dps310;
    return isfinite(reading.pressureHpa) && isfinite(reading.temperatureC) &&
           reading.pressureHpa >= kMinPressureHpa && reading.pressureHpa <= kMaxPressureHpa &&
           reading.temperatureC >= kMinTemperatureC && reading.temperatureC <= kMaxTemperatureC;
  }

  bool fail() {
    ++errorCount_;
    if (++failures_ >= config::dps310::kMaxConsecutiveFailures) {
      active_ = nullptr;
      lastAttemptMs_ = nowMs();
    }
    return false;
  }
};

EnvironmentX6 environmentSensor(Serial1);
DustSensor dustSensor(config::dust::kLedPin, config::dust::kOutputPin);
PressureSensorDps310 pressureSensor(Wire);

LiveValue<EnvironmentReading> environment;
LiveValue<DustReading> dust;
LiveValue<PressureReading> pressure;

template <typename Sensor, typename Reading>
void poll(Sensor& sensor, LiveValue<Reading>& channel) {
  Reading reading{};
  if (sensor.read(reading)) channel.update(reading);
}

void pollSensors() {
  poll(environmentSensor, environment);
  poll(dustSensor, dust);
  poll(pressureSensor, pressure);
}

struct CsvField {
  float value;
  uint8_t decimals;
};

void printCsvRecord() {
  const EnvironmentReading& env = environment.value();
  const CsvField fields[] = {
      {env.iaq, 2},
      {env.tvocPpm, 3},
      {env.hchoPpm, 3},
      {env.coPpm, 3},
      {env.temperatureC, 2},
      {env.humidityPct, 2},
      {dust.value().densityUgm3, 1},
      {pressure.value().pressureHpa, 2},
      {pressure.value().altitudeM, 1},
  };

  for (size_t i = 0; i < sizeof(fields) / sizeof(fields[0]); ++i) {
    if (i > 0) Serial.print(',');
    Serial.print(fields[i].value, fields[i].decimals);
  }
  Serial.println();
}

void printMetric(const char* label, float value, uint8_t decimals, const char* unit) {
  Serial.print(label);
  Serial.print(' ');
  Serial.print(value, decimals);
  Serial.print(unit);
  Serial.print("  ");
}

void printValues(const EnvironmentReading& r) {
  printMetric("IAQ", r.iaq, 2, "");
  printMetric("TVOC", r.tvocPpm, 3, " ppm");
  printMetric("HCHO", r.hchoPpm, 3, " ppm");
  printMetric("CO", r.coPpm, 3, " ppm");
  printMetric("T", r.temperatureC, 2, " C");
  printMetric("RH", r.humidityPct, 2, " %");
}

void printValues(const DustReading& r) {
  printMetric("PM", r.densityUgm3, 1, " ug/m3");
}

void printValues(const PressureReading& r) {
  printMetric("P", r.pressureHpa, 2, " hPa");
  printMetric("T", r.temperatureC, 2, " C");
  printMetric("ALT", r.altitudeM, 1, " m");
}

template <typename T>
void printChannel(const char* name, LiveValue<T>& channel, uint32_t errors, uint32_t windowMs) {
  const char* state = !channel.hasValue() ? "WAIT " : channel.isFresh() ? "LIVE " : "STALE";
  const float rateHz = channel.takeUpdateCount() * 1000.0f / windowMs;

  Serial.print(name);
  Serial.print("  ");
  Serial.print(state);
  Serial.print("  age ");
  Serial.print(static_cast<unsigned long>(channel.ageMs()));
  Serial.print(" ms  rate ");
  Serial.print(rateHz, 1);
  Serial.print(" Hz  err ");
  Serial.print(static_cast<unsigned long>(errors));
  Serial.print("  | ");
  printValues(channel.value());
  Serial.println();
}

void reportDiagnostics() {
  static uint32_t lastReportMs = nowMs();
  const uint32_t now = nowMs();
  const uint32_t windowMs = now - lastReportMs;
  if (windowMs < config::kDiagnosticsIntervalMs) return;
  lastReportMs = now;

  Serial.print("--- Atmosis @ ");
  Serial.print(now / 1000.0f, 1);
  Serial.println(" s ---");
  printChannel("X6    ", environment, environmentSensor.errorCount(), windowMs);
  printChannel("DUST  ", dust, dustSensor.errorCount(), windowMs);
  printChannel("DPS310", pressure, pressureSensor.errorCount(), windowMs);
}

void setup() {
  Serial.begin(config::kSerialBaud);
  const uint32_t start = nowMs();
  while (!Serial && nowMs() - start < config::kSerialWaitMs) delay(10);

  analogReadResolution(config::adc::kResolutionBits);
  environmentSensor.begin();
  dustSensor.begin();
  pressureSensor.begin();
}

void loop() {
  static uint32_t lastPollMs = 0;
  const uint32_t now = nowMs();
  if (now - lastPollMs < config::kPollIntervalMs) {
    delay(1);
    return;
  }
  lastPollMs = now;

  pollSensors();

  if (config::kDiagnosticsMode) {
    reportDiagnostics();
  } else {
    printCsvRecord();
  }
}

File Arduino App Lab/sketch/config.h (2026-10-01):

#pragma once
#include <Arduino.h>

#define ATMOSIS_VERSION "1.2"

constexpr uint32_t FRAME_INTERVAL_MS        = 1000;
constexpr uint32_t INFO_INTERVAL_MS         = 30000;
constexpr uint32_t INFO_FIRST_MS            = 3000;
constexpr uint32_t LOOP_YIELD_MS            = 4;
constexpr uint8_t  FRAME_PROTOCOL           = 5;
constexpr uint8_t  FIRMWARE_CODE            = 12;

#define X6_SERIAL Serial1
constexpr uint32_t X6_BAUD                  = 9600;
constexpr uint8_t  X6_CMD_CONCENTRATION     = 0x70;
constexpr uint8_t  X6_RESPONSE_LEN          = 22;
constexpr uint32_t X6_POLL_INTERVAL_MS      = 1000;
constexpr uint32_t X6_FRAME_TIMEOUT_MS      = 250;
constexpr uint32_t X6_STALE_AFTER_MS        = 3500;
constexpr float    X6_IAQ_MAX               = 500.0f;
constexpr float    X6_TVOC_MAX              = 10.0f;
constexpr float    X6_HCHO_MAX              = 2.0f;
constexpr float    X6_CO_MAX                = 200.0f;
constexpr float    X6_TEMP_MIN              = -40.0f;
constexpr float    X6_TEMP_MAX              = 85.0f;

constexpr uint8_t  PIN_DUST_ILED            = 4;
constexpr uint8_t  PIN_DUST_AOUT            = A0;
constexpr float    DUST_VOLTAGE_GAIN        = 11.0f;
constexpr float    DUST_ZERO_MV             = 400.0f;
constexpr float    DUST_UGM3_PER_MV         = 0.2f;
constexpr float    DUST_MAX_UGM3            = 500.0f;
constexpr uint32_t DUST_BATCH_INTERVAL_MS   = 1000;
constexpr uint8_t  DUST_SAMPLES             = 10;
constexpr uint8_t  DUST_AVERAGE_WINDOW      = 10;
constexpr uint32_t DUST_SAMPLE_DELAY_US     = 280;
constexpr uint32_t DUST_PULSE_MAX_US        = 1200;
constexpr uint32_t DUST_PULSE_PERIOD_US     = 10000;
constexpr float    DUST_NO_SIGNAL_MV        = 4.0f;

constexpr uint8_t  ADC_RESOLUTION_BITS      = 12;
constexpr uint32_t ADC_MAX_COUNT            = (1UL << ADC_RESOLUTION_BITS) - 1UL;
constexpr float    ADC_VREF                 = 3.3f;

#define DPS310_WIRE Wire
constexpr uint32_t I2C_CLOCK_HZ             = 100000;
constexpr uint32_t PRESSURE_POLL_MS         = 1000;
constexpr uint32_t PRESSURE_RETRY_MS        = 10000;
constexpr float    PRESSURE_MIN_HPA         = 300.0f;
constexpr float    PRESSURE_MAX_HPA         = 1200.0f;
constexpr float    SEA_LEVEL_PRESSURE_HPA   = 1013.25f;

constexpr uint8_t  PIN_WS2812B              = 5;
constexpr uint16_t WS2812B_LED_COUNT        = 30;
constexpr uint8_t  WS2812B_BRIGHTNESS       = 40;
constexpr uint32_t LED_FADE_MS              = 600;
constexpr uint32_t LED_FRAME_MS             = 40;
constexpr uint32_t LED_PULSE_PERIOD_MS      = 1600;

constexpr float    DUST_ALERT_UGM3          = 150.0f;
constexpr float    DUST_ALERT_CLEAR_UGM3    = 130.0f;
constexpr float    CO_ALERT_PPM             = 9.0f;
constexpr float    CO_ALERT_CLEAR_PPM       = 8.0f;

constexpr uint16_t FLAG_X6                  = 0x0001;
constexpr uint16_t FLAG_PRESSURE            = 0x0002;
constexpr uint16_t FLAG_DUST                = 0x0004;
constexpr uint16_t FLAG_DUST_TIME           = 0x0008;
constexpr uint16_t FLAG_FAILSAFE            = 0x0010;
constexpr uint16_t FLAG_CO_ALARM            = 0x0020;
constexpr uint16_t FLAG_LED                 = 0x0040;

static_assert(DUST_SAMPLES >= 5, "Need enough pulses per batch");
static_assert(DUST_ALERT_CLEAR_UGM3 < DUST_ALERT_UGM3, "Dust hysteresis must be positive");
static_assert(CO_ALERT_CLEAR_PPM < CO_ALERT_PPM, "CO hysteresis must be positive");
static_assert(DUST_SAMPLE_DELAY_US == 280, "Sharp/Waveshare sample point is 280 us after the LED turns on");
static_assert(WS2812B_LED_COUNT > 0 && WS2812B_LED_COUNT <= 60, "Keep the strip short for Bridge timing and USB power");
static_assert(PRESSURE_MIN_HPA < PRESSURE_MAX_HPA, "Pressure bounds ordered");

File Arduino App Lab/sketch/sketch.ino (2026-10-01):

#include <Arduino_RouterBridge.h>
#include "config.h"
#include "sensors.h"
#include "status_led.h"
#include "air_score.h"

namespace {

EnvironmentX6  x6Sensor;
DustSensor     dustSensor;
PressureSensor pressureSensor;
StatusLed      statusLed;

X6Reading   lastX6;
DustReading lastDust;
bool        dustAlarm       = false;
bool        coAlarm         = false;
uint32_t    frameSeq        = 0;
uint32_t    nextFrameMs     = 0;
uint32_t    nextInfoMs      = 0;
uint32_t    loopStartMs     = 0;
uint32_t    loopMaxMs       = 0;
uint32_t    loopMaxWindowMs = 0;
uint32_t    loopMaxReported = 0;

int pressureChipCode() {
  return pressureSensor.detected() ? 3 : 0;
}

int statusFlags() {
  int f = 0;
  if (lastX6.valid)                   f |= FLAG_X6;
  if (pressureSensor.reading().valid) f |= FLAG_PRESSURE;
  if (lastDust.valid)                 f |= FLAG_DUST;
  if (lastDust.timing_ok)             f |= FLAG_DUST_TIME;
  if (dustAlarm)                      f |= FLAG_FAILSAFE;
  if (coAlarm)                        f |= FLAG_CO_ALARM;
  if (statusLed.ready())              f |= FLAG_LED;
  return f;
}

void updateAlarmsAndLight() {
  if (lastX6.valid) {
    if (lastX6.co_ppm >= CO_ALERT_PPM) coAlarm = true;
    else if (lastX6.co_ppm <= CO_ALERT_CLEAR_PPM) coAlarm = false;
  }
  statusLed.setAlarm(dustAlarm || coAlarm);
  const int score = airScore(lastX6.valid, lastX6.iaq, lastX6.tvoc_ppm, lastX6.hcho_ppm, lastX6.co_ppm,
                             lastDust.valid, lastDust.density_ugm3);
  uint8_t r, g, b;
  scoreColor(score, r, g, b);
  statusLed.setColor(r, g, b);
}

void pushFrame(uint32_t now) {
  const PressureReading& p = pressureSensor.reading();
  Bridge.notify("atmosis_frame",
                (int)FRAME_PROTOCOL,
                (int)(++frameSeq),
                (int)(now / 1000UL),
                statusFlags(),
                lastX6.iaq,
                lastX6.tvoc_ppm,
                lastX6.hcho_ppm,
                lastX6.co_ppm,
                lastX6.temperature_c,
                lastX6.humidity_pct,
                lastDust.density_ugm3,
                (int)(lastDust.sensor_v * 1000.0f + 0.5f),
                (int)DUST_ZERO_MV,
                (int)lastDust.status,
                p.pressure_hpa,
                p.altitude_m,
                p.temperature_c,
                pressureChipCode(),
                (int)loopMaxReported);
}

void pushInfo() {
  Bridge.notify("atmosis_info",
                (int)FRAME_PROTOCOL,
                (int)FIRMWARE_CODE,
                (int)x6Sensor.framesOk(),
                (int)x6Sensor.framesBad(),
                (int)x6Sensor.status(),
                (int)pressureSensor.status(),
                pressureChipCode(),
                (int)pressureSensor.address(),
                (int)pressureSensor.idByte(),
                (int)pressureSensor.attempts(),
                (int)lastDust.status,
                (int)(lastDust.pin_mv * 10.0f + 0.5f),
                1,
                statusLed.ready() ? 1 : 0,
                (int)WS2812B_LED_COUNT);
}

void trackLoopTime(uint32_t now) {
  const uint32_t elapsed = now - loopStartMs;
  loopStartMs = now;
  if (elapsed > loopMaxMs) loopMaxMs = elapsed;
  if ((now - loopMaxWindowMs) >= 5000) {
    loopMaxReported = loopMaxMs;
    loopMaxMs = 0;
    loopMaxWindowMs = now;
  }
}

}

void setup() {
  Bridge.begin();
  analogReadResolution(ADC_RESOLUTION_BITS);
  x6Sensor.begin();
  dustSensor.begin();
  pressureSensor.begin();
  statusLed.begin();

  const uint32_t now = millis();
  loopStartMs     = now;
  loopMaxWindowMs = now;
  nextFrameMs     = now + FRAME_INTERVAL_MS;
  nextInfoMs      = now + INFO_FIRST_MS;
}

void loop() {
  const uint32_t now = millis();
  trackLoopTime(now);

  statusLed.update(now);
  x6Sensor.poll(now);
  lastX6 = x6Sensor.reading(now);
  dustSensor.poll(now);
  pressureSensor.update(now);

  DustReading dust;
  if (dustSensor.consume(dust)) {
    lastDust = dust;
    if (dust.valid) {
      if (dust.density_ugm3 >= DUST_ALERT_UGM3) dustAlarm = true;
      else if (dust.density_ugm3 <= DUST_ALERT_CLEAR_UGM3) dustAlarm = false;
    } else if (dust.status == DUST_STATUS_SATURATED) {
      dustAlarm = true;
    } else if (dust.status == DUST_STATUS_NO_SIGNAL) {
      dustAlarm = false;
    }
  }

  if ((int32_t)(now - nextFrameMs) >= 0) {
    nextFrameMs += FRAME_INTERVAL_MS;
    if ((int32_t)(now - nextFrameMs) >= 0) nextFrameMs = now + FRAME_INTERVAL_MS;
    updateAlarmsAndLight();
    pushFrame(now);
  }

  if ((int32_t)(now - nextInfoMs) >= 0) {
    nextInfoMs = now + INFO_INTERVAL_MS;
    pushInfo();
  }

  delay(LOOP_YIELD_MS);
}

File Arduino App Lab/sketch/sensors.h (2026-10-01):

#pragma once
#include <Arduino.h>
#include <Wire.h>
#include <Adafruit_DPS310.h>
#include <string.h>
#include "config.h"

enum X6Status : uint8_t { X6_STARTING = 0, X6_OK = 1, X6_TIMEOUT = 2, X6_CHECKSUM = 3, X6_OUT_OF_RANGE = 4 };
enum PressureStatus : uint8_t { P_NOT_DETECTED = 0, P_OK = 1, P_INIT_FAILED = 2, P_UNKNOWN_CHIP = 3, P_LOST = 4 };

struct X6Reading {
  float iaq           = 0;
  float tvoc_ppm      = 0;
  float hcho_ppm      = 0;
  float co_ppm        = 0;
  float temperature_c = 0;
  float humidity_pct  = 0;
  bool  valid         = false;
};

class EnvironmentX6 {
public:
  void begin() {
    X6_SERIAL.begin(X6_BAUD);
    drain();
    state_ = State::Idle;
  }

  void poll(uint32_t now) {
    if (state_ == State::AwaitingFrame) {
      collect();
      if (state_ == State::AwaitingFrame && (now - queryAtMs_) > X6_FRAME_TIMEOUT_MS) {
        state_ = State::Idle;
        timeouts_++;
        status_ = X6_TIMEOUT;
      }
      return;
    }
    if ((now - lastQueryMs_) < X6_POLL_INTERVAL_MS) return;
    sendQuery(now);
  }

  X6Reading reading(uint32_t now) const {
    X6Reading r = last_;
    if (r.valid && (now - lastGoodMs_) > X6_STALE_AFTER_MS) r.valid = false;
    return r;
  }

  uint8_t     status()    const { return status_; }
  uint32_t    framesOk()  const { return framesOk_; }
  uint32_t    framesBad() const { return framesBad_ + timeouts_; }

private:
  enum class State : uint8_t { Idle, AwaitingFrame };

  State       state_       = State::Idle;
  uint8_t     buffer_[X6_RESPONSE_LEN] = {0};
  uint8_t     filled_      = 0;
  uint32_t    lastQueryMs_ = 0;
  uint32_t    queryAtMs_   = 0;
  uint32_t    lastGoodMs_  = 0;
  uint32_t    framesOk_    = 0;
  uint32_t    framesBad_   = 0;
  uint32_t    timeouts_    = 0;
  uint8_t     status_      = X6_STARTING;
  X6Reading   last_;

  void drain() {
    while (X6_SERIAL.available() > 0) X6_SERIAL.read();
  }

  static uint8_t checksum(const uint8_t* data, size_t len) {
    uint32_t sum = 0;
    for (size_t i = 0; i < len; ++i) sum += data[i];
    return (uint8_t)((~(sum & 0xFF) + 1) & 0xFF);
  }

  static float bigEndianFloat(const uint8_t* p) {
    const uint32_t bits = ((uint32_t)p[0] << 24) | ((uint32_t)p[1] << 16) |
                          ((uint32_t)p[2] << 8)  |  (uint32_t)p[3];
    float value;
    memcpy(&value, &bits, sizeof(value));
    return value;
  }

  void sendQuery(uint32_t now) {
    drain();
    const uint8_t command[2] = { X6_CMD_CONCENTRATION, checksum(&X6_CMD_CONCENTRATION, 1) };
    X6_SERIAL.write(command, sizeof(command));
    filled_      = 0;
    queryAtMs_   = now;
    lastQueryMs_ = now;
    state_       = State::AwaitingFrame;
  }

  void collect() {
    while (X6_SERIAL.available() > 0) {
      const int byteIn = X6_SERIAL.read();
      if (byteIn < 0) break;
      if (filled_ == 0 && (uint8_t)byteIn != X6_CMD_CONCENTRATION) continue;
      buffer_[filled_++] = (uint8_t)byteIn;
      if (filled_ < X6_RESPONSE_LEN) continue;
      filled_ = 0;
      state_  = State::Idle;
      decode();
      return;
    }
  }

  void decode() {
    uint32_t sum = 0;
    for (uint8_t i = 0; i < X6_RESPONSE_LEN; ++i) sum += buffer_[i];
    if ((sum & 0xFF) != 0) {
      framesBad_++;
      status_ = X6_CHECKSUM;
      return;
    }
    X6Reading r;
    r.iaq           = bigEndianFloat(&buffer_[1]);
    r.tvoc_ppm      = bigEndianFloat(&buffer_[5]);
    r.hcho_ppm      = bigEndianFloat(&buffer_[9]);
    r.co_ppm        = bigEndianFloat(&buffer_[13]);
    r.temperature_c = (float)(int16_t)(((uint16_t)buffer_[17] << 8) | buffer_[18]) / 100.0f;
    r.humidity_pct  = (float)(((uint16_t)buffer_[19] << 8) | buffer_[20]) / 100.0f;
    if (!plausible(r)) {
      framesBad_++;
      status_ = X6_OUT_OF_RANGE;
      return;
    }
    r.valid     = true;
    last_       = r;
    lastGoodMs_ = millis();
    framesOk_++;
    status_     = X6_OK;
  }

  static bool plausible(const X6Reading& r) {
    if (!isfinite(r.iaq) || !isfinite(r.tvoc_ppm) || !isfinite(r.hcho_ppm) || !isfinite(r.co_ppm)) return false;
    if (r.iaq < 0 || r.iaq > X6_IAQ_MAX) return false;
    if (r.tvoc_ppm < 0 || r.tvoc_ppm > X6_TVOC_MAX) return false;
    if (r.hcho_ppm < 0 || r.hcho_ppm > X6_HCHO_MAX) return false;
    if (r.co_ppm < 0 || r.co_ppm > X6_CO_MAX) return false;
    if (r.temperature_c < X6_TEMP_MIN || r.temperature_c > X6_TEMP_MAX) return false;
    if (r.humidity_pct < 0 || r.humidity_pct > 100) return false;
    return true;
  }
};

enum DustStatus : uint8_t {
  DUST_STATUS_STARTING  = 0,
  DUST_STATUS_OK        = 1,
  DUST_STATUS_NO_SIGNAL = 2,
  DUST_STATUS_SATURATED = 3,
};

struct DustReading {
  float   density_ugm3 = 0;
  float   sensor_v     = 0;
  float   pin_mv       = 0;
  uint8_t status       = DUST_STATUS_STARTING;
  bool    valid        = false;
  bool    timing_ok    = true;
};

inline float dustDensityFromSensorMv(float sensorMv) {
  if (sensorMv <= DUST_ZERO_MV) return 0.0f;
  const float d = (sensorMv - DUST_ZERO_MV) * DUST_UGM3_PER_MV;
  return d > DUST_MAX_UGM3 ? DUST_MAX_UGM3 : d;
}
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
